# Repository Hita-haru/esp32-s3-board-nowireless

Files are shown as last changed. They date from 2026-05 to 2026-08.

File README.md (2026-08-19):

# ESP32-S3-NoWireless-board
## Description
This is a devboard built using just the ESP32-S3 chip.
## Reason for Creation
Given the ESP32-S3’s AI capabilities and high performance, I wanted to create a program that connects a camera and analyzes its footage using  
AI. However, most inexpensive development boards lack technical compliance certification, and without it, powering them on in Japan would be illegal, forcing me to use a more expensive model.  
This makes it difficult to popularize affordable AI cameras, which is why I decided to build this.  

## How to assemble
1. Manufacture or order the components and circuit board.
2. Solder the components to the circuit board with all your might.
3. Connect it to a computer using a Type-C cable and flash the firmware.
4. After that, you’re free to use it however you like.

## How to Flash Firmware to Custom ESP32-S3 via Arduino IDE
1. Install Board Package
Open Arduino IDE and go to Preferences.

Add this URL to Additional Boards Manager URLs:

[https://raw.githubusercontent.com/espressif/arduino-esp32/gh-pages/package_esp32_index.json](https://raw.githubusercontent.com/espressif/arduino-esp32/gh-pages/package_esp32_index.json)

Open Tools > Board > Boards Manager, search for esp32, and install it.

2. Select Board Settings
Board: ESP32S3 Dev Module

USB CDC On Boot: Enabled (Crucial if using direct ESP32-S3 USB pins IO19/IO20 for Serial output)

Port: Select your board's COM port.

3. Enter Download (Bootloader) Mode
(If your custom board does not have an auto-reset circuit)

Press and HOLD the BOOT button (GPIO0).

Press and RELEASE the RESET (EN) button.

RELEASE the BOOT button.

4. Upload
Click the Upload button in Arduino IDE.

Once the upload is complete, press the RESET button once to run your code!

## Pictures
### Schematic
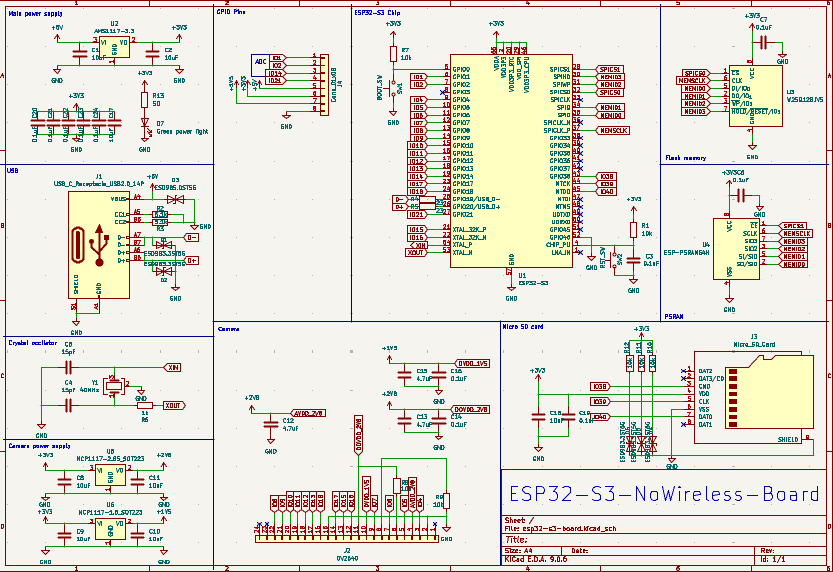
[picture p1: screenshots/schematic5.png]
Schematic

### PCB
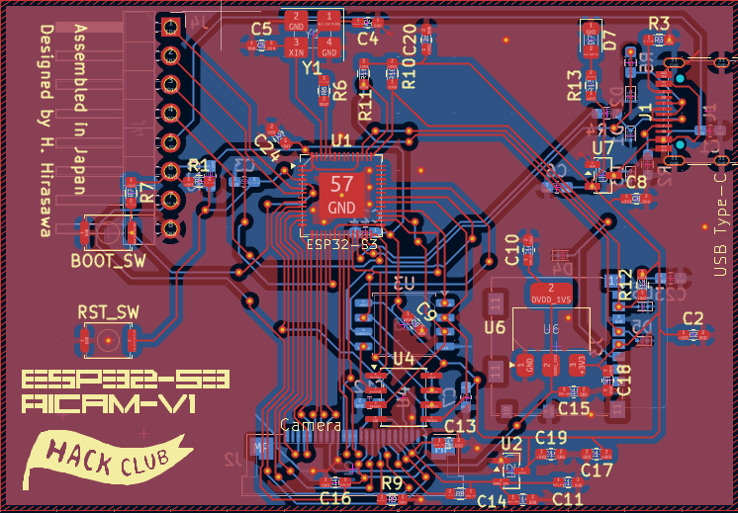
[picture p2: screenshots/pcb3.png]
PCB

### 3D
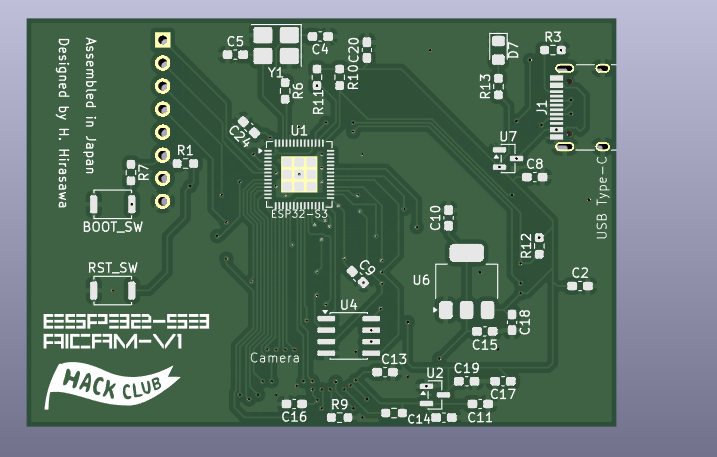
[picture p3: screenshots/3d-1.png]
3D-1

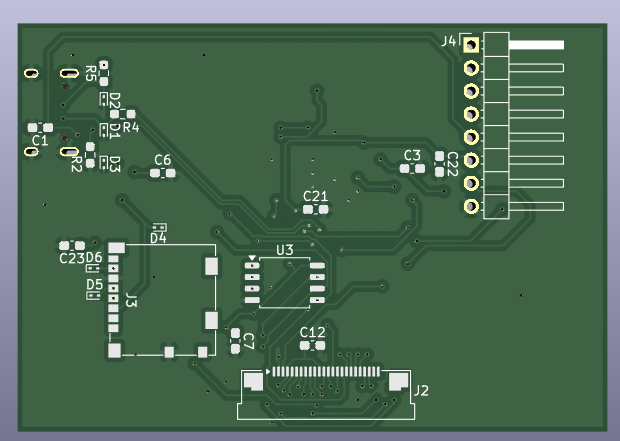
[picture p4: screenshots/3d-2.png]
3D-2

### Estimates
- JLCPCB  
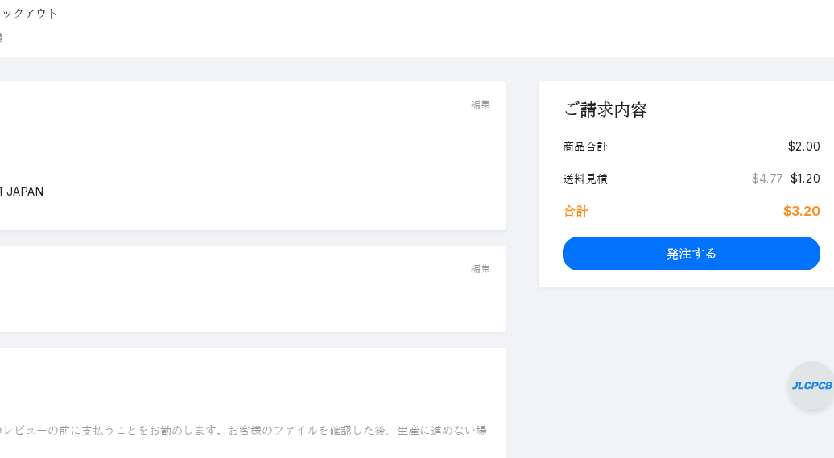
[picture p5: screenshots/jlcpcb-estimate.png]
JLCPCB Estimate1
  
**Shipping options**  
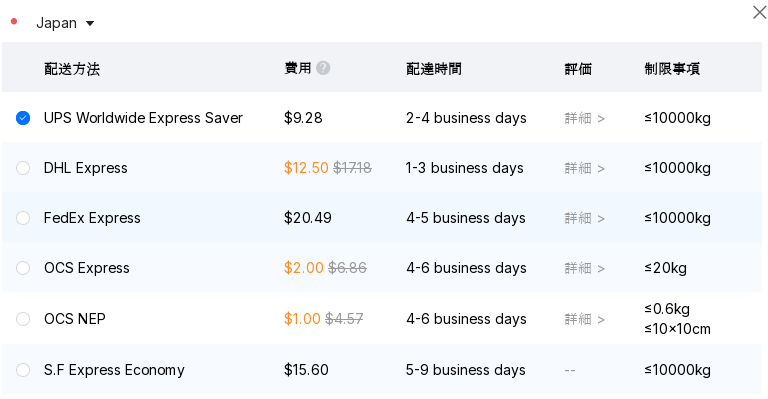
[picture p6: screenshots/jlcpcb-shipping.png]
JLCPCB Estimate2
  
- LCSC  
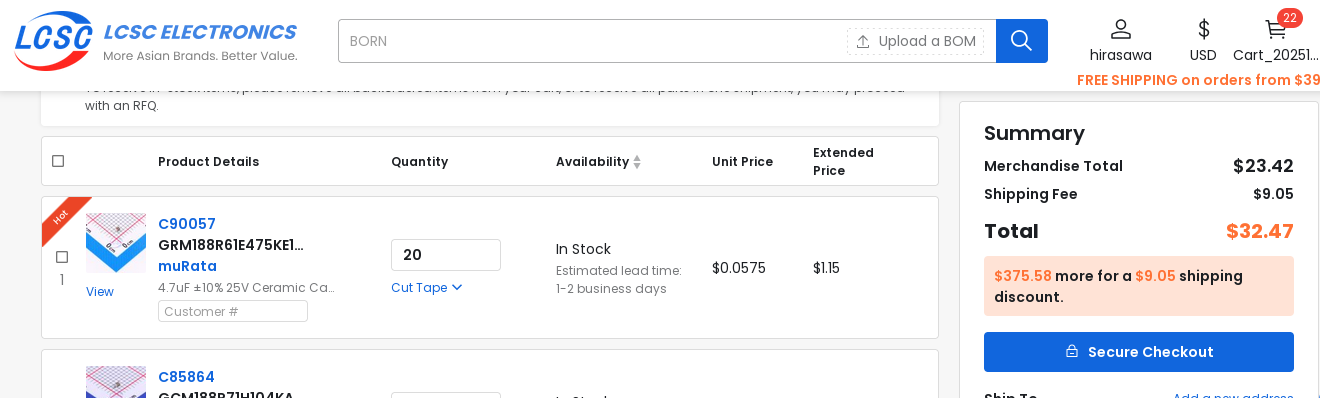
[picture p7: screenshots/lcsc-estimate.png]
LCSC Estimate1
  
**Shipping options**  
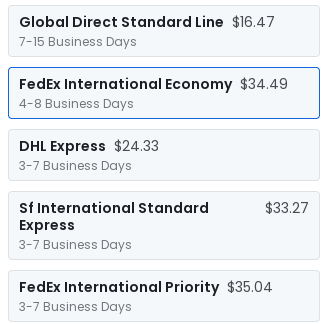
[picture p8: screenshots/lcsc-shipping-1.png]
LCSC Estimate2

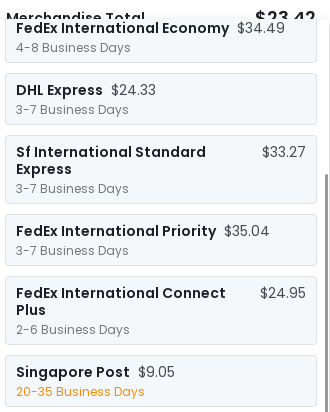
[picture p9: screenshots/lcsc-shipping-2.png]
LCSC Estimate3
  
- Aliexpress  
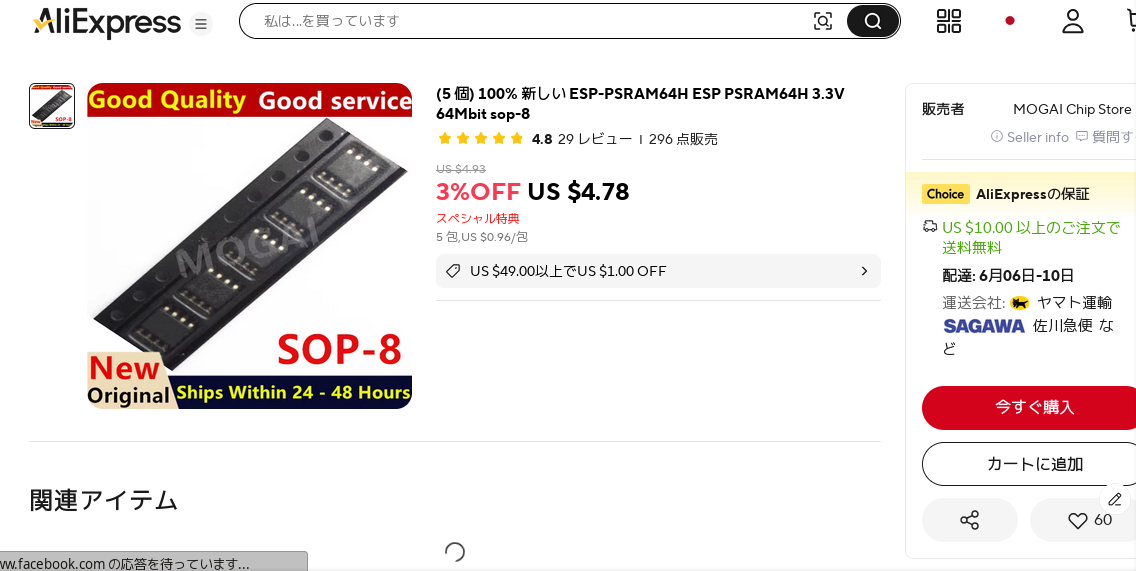
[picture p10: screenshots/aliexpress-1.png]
Aliexpress Estimate1
  
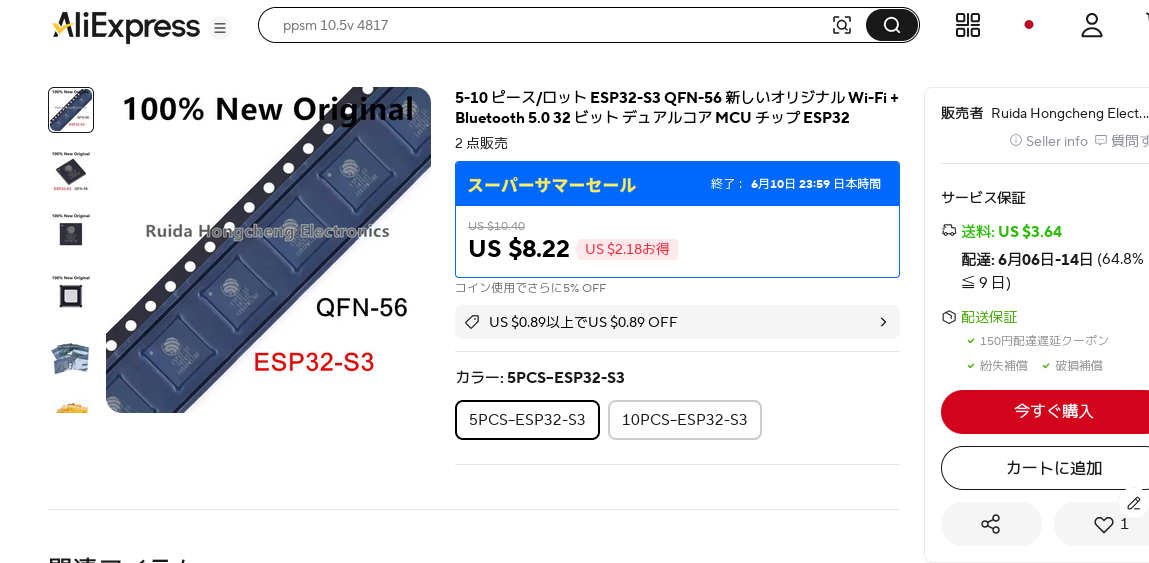
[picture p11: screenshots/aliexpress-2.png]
Aliexpress Estimate2
  

## Cost details
### LCSC
- Subtotal for items  
*23.51* USD  
- Shipping fee (to Japan)  
*9.05* USD
- **Total**  
*32.50* USD (Including discount)  
### Aliexpress
- Subtotal for items  
*13.14* USD  
- Shipping fee (to Japan)  
*5.62* USD  
- **Total**  
*18.76* USD  
### JLCPCB
- Subtotal for items  
*4.00* USD  
- Shipping fee (to Japan)  
*1.00* USD (Including discount)  
- **Total**  
*5.00* USD (Including discount)  

## BOM
| No. | リファレンス (Designators) | 部品名 / 値 (Value) | フットプリント (Footprint) | 数量 | 単価 ($) | URL |
|:---|:---|:---|:---|:---|:---|:---|
| 1 | C13, C15, C12 | 4.7uF | C_0603_1608Metric_Pad1.08x0.95mm_HandSolder | 3 | 0.0675 | https://www.lcsc.com/product-detail/C90057.html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 |
| 2 | C16, C14, C19, C20, C24, C7, C22, C21, C23, C6, C3 | 0.1uF | C_0603_1608Metric_Pad1.08x0.95mm_HandSolder | 11 | 0.0161 | https://www.lcsc.com/product-detail/C85864.html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 |
| 3 | R7, R12, R11, R9, R1, R10, R8 | 10k | R_0603_1608Metric_Pad0.98x0.95mm_HandSolder | 7 | 0.0038 | https://www.lcsc.com/product-detail/C130232.html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 |
| 4 | C9, C8, C10, C17, C2, C18, C11, C1 | 10uF | C_0603_1608Metric_Pad1.08x0.95mm_HandSolder | 8 | 0.0230 | https://www.lcsc.com/product-detail/C7307463.html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 |
| 5 | U6 | NCP1117-1.5_SOT223 | SOT-223-3_TabPin2 | 1 | 0.0684 | https://www.lcsc.com/product-detail/C5380421.html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 |
| 6 | RST_SW | RST_SW | SW_Push_SPST_NO_Alps_SKRK | 1 | 0.1457 | https://www.lcsc.com/product-detail/C202388.html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 |
| 7 | U7 | MCP1700x-330xxTT | SOT-23 | 1 | 0.0886 | https://www.lcsc.com/product-detail/C7551026.html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 |
| 8 | Y1 | 40MHz | Crystal_SMD_3225-4Pin_3.2x2.5mm_HandSoldering | 1 | 0.2632 | https://www.lcsc.com/product-detail/C255943.html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 |
| 9 | R13 | 50 | R_0603_1608Metric_Pad0.98x0.95mm_HandSolder | 1 | 0.0312 | https://www.lcsc.com/product-detail/C849792.html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 |
| 10 | U1 | ESP32-S3 | QFN-56-1EP_7x7mm_P0.4mm_EP4x4mm | 1 | 1.64 | https://ja.aliexpress.com/item/1005012279323107.html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 |
| 11 | R6 | 1k | R_0603_1608Metric_Pad0.98x0.95mm_HandSolder | 1 | 0.0066 | https://www.lcsc.com/product-detail/C118155.html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 |
| 12 | C4, C5 | 15pF | C_0603_1608Metric_Pad1.08x0.95mm_HandSolder | 2 | 0.0066 | https://www.lcsc.com/product-detail/C71651.html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 |
| 13 | U2 | MCP1700x-280xxTT | SOT-23 | 1 | 0.0354 | https://www.lcsc.com/product-detail/C236702.html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 |
| 14 | BOOT_SW | BOOT_SW | SW_Push_SPST_NO_Alps_SKRK | 1 | 0.1457 | https://www.lcsc.com/product-detail/C202388.html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 |
| 15 | J1 | USB_C_Receptacle_USB2.0_14P | USB_C_Receptacle_HRO_TYPE-C-31-M-12 | 1 | 0.1870 | https://www.lcsc.com/product-detail/C165948.html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 |
| 16 | D7 | Green power light | LED_0805_2012Metric_Pad1.15x1.40mm_HandSolder | 1 | 0.0332 | https://www.lcsc.com/product-detail/C192319.html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 |
| 17 | R3, R2 | 5.1k | R_0603_1608Metric_Pad0.98x0.95mm_HandSolder | 2 | 0.0078 | https://www.lcsc.com/product-detail/C160048.html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 |
| 18 | U4 | ESP-PSRAM64H | SOIC-8_3.9x4.9mm_P1.27mm | 1 | 0.956 | https://ja.aliexpress.com/item/1005009178803030.html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 |
| 19 | D6, D2, D4, D5, D1 | ESD9B3.3ST5G | D_SOD-923 | 5 | 0.0154 | https://www.lcsc.com/product-detail/C51898359.html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 |
| 20 | J3 | Micro_SD_Card | microSD_HC_Molex_104031-0811 | 1 | 0.6804 | https://www.lcsc.com/product-detail/C585350.html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 |
| 21 | R5, R4 | 23 | R_0603_1608Metric_Pad0.98x0.95mm_HandSolder | 2 | 0.0020 | https://www.lcsc.com/product-detail/C2612468.html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 |
| 22 | U3 | W25Q128JVS | SOIC-8_5.3x5.3mm_P1.27mm | 1 | 2.6399 | https://www.lcsc.com/product-detail/C97521.html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 |
| 23 | J4 | Conn_01x08 | PinHeader_1x08_P2.54mm_Horizontal | 1 | 0.0734 | https://www.lcsc.com/product-detail/C7501270.html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 |
| 24 | J2 | OV2640 | Amphenol_F32Q-1A7x1-11024_1x24-1MP_P0.5mm_Horizontal | 1 | 2.1342 | https://www.lcsc.com/product-detail/C3168917.html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 |
| 25 | D3 | ESD9B5.0ST5G | D_SOD-923 | 1 | 0.0457 | https://www.lcsc.com/product-detail/C82326.html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 |
| 26 | - | PCB | - | 1 | 0.8 | https://cart.jlcpcb.com/jp/quote |

## Credits & Acknowledgements
This hardware design is based on / derived from the [ESP32-S3-EYE](https://github.com/espressif/esp-dev-kits) reference design created by **Espressif Systems**. Special thanks to Espressif for providing open-source hardware reference designs.

## Trademarks
- "ESP32", "ESP32-S3", and "Espressif" are registered trademarks or trademarks of **Espressif Systems (Shanghai) Co., Ltd.**
- All other trademarks and logos are the property of their respective owners.

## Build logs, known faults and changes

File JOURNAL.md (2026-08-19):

---
title: "ESP32-S3-board-nowireless"
author: "ひらさわ"
description: "This is ESP32-S3 devboard"
created_at: "2026-05-20"
---

# 5/20: Created project and designed schematic
I Created project and Kicad files.  
I’ve drawn up a schematic as well. At first, I was thinking of using WROOM, but since the versions with Technical Conformity Mark are expensive, To reduce costs, we opted for the standalone chip instead of the ESP32-S3 WROOM module.  

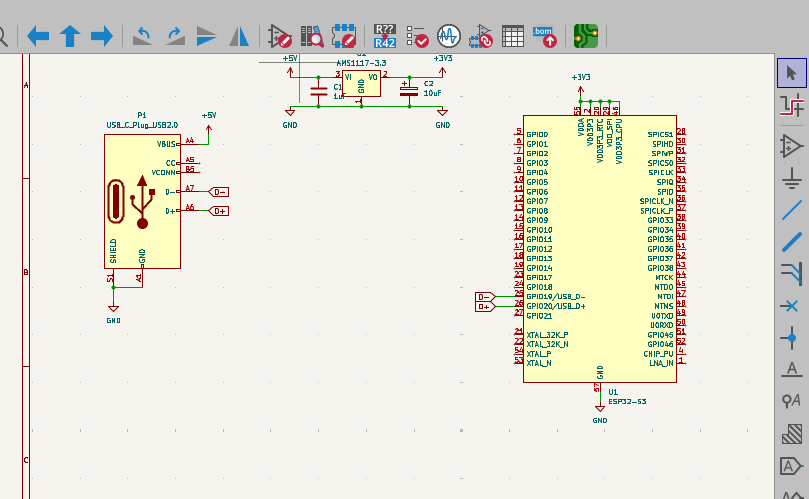
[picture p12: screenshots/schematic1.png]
schematic
  
**Total time spent: 2 hours**

# 5/22: Set up git and added crystal oscillator and so on
I set up GitHub.  
I also added a crystal oscillator and modified the USB connector.  
Unfortunately, there wasn’t much documentation available, so I ended up spending quite a bit of time searching for information.  

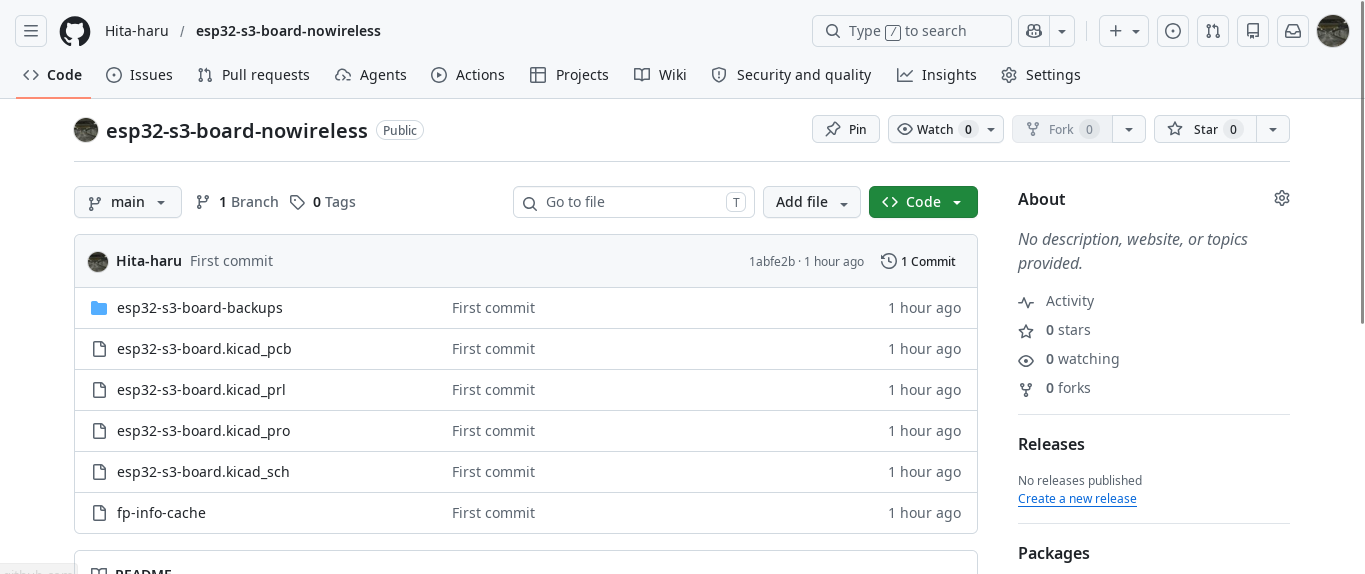
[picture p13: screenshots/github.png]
Github

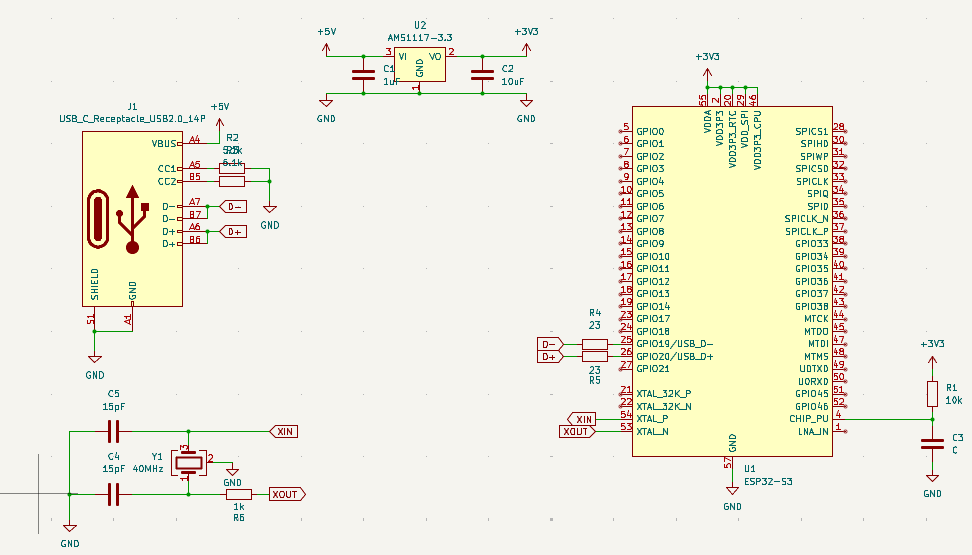
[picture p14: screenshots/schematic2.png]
Schematic
  
**Total time spent: 2 hours**

# 5/23: Added flash memory and PSRAM to the schematic
I added flash memory and PSRAM to the circuit diagram.  
As usual, there was no detailed documentation, so I added them while referring to the Blueprint's guide.  
Other than that, I just added a connector for attaching a camera.  
It took me forever to find the documentation, so it was a real hassle.  

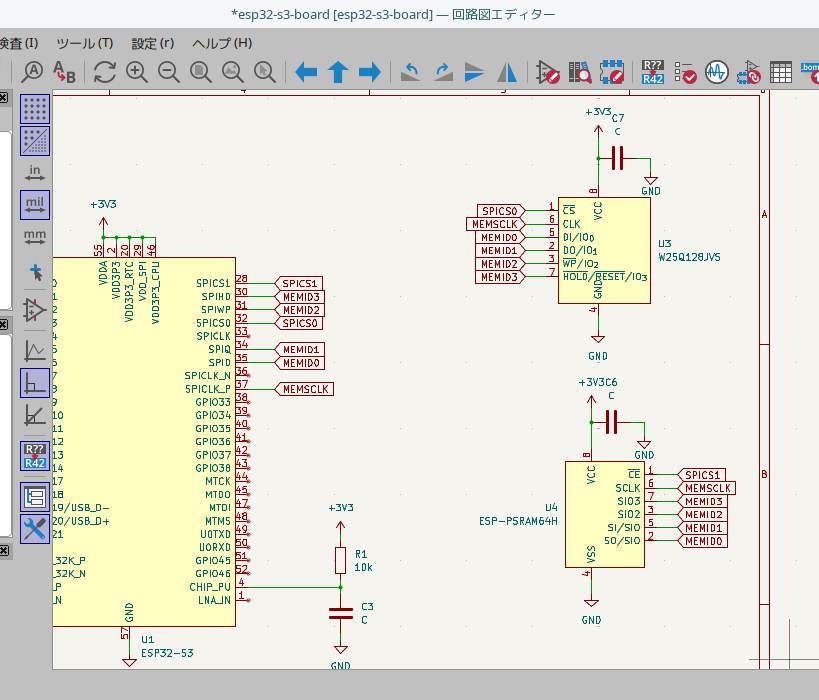
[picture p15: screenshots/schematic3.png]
Schematic
  
**Total time spent: 2 hours**

# 5/26: Added camera and power supply to the schematic
Today, I added the camera module (24-pin FPC connector for the OV2640) and the power supply module for the 3.3V line (such as the AMS1117-3.3) to the circuit diagram, using the ESP32-S3-EYE circuit diagram as a reference.  
I think it will be quite difficult because there will likely be a lot of noise.  

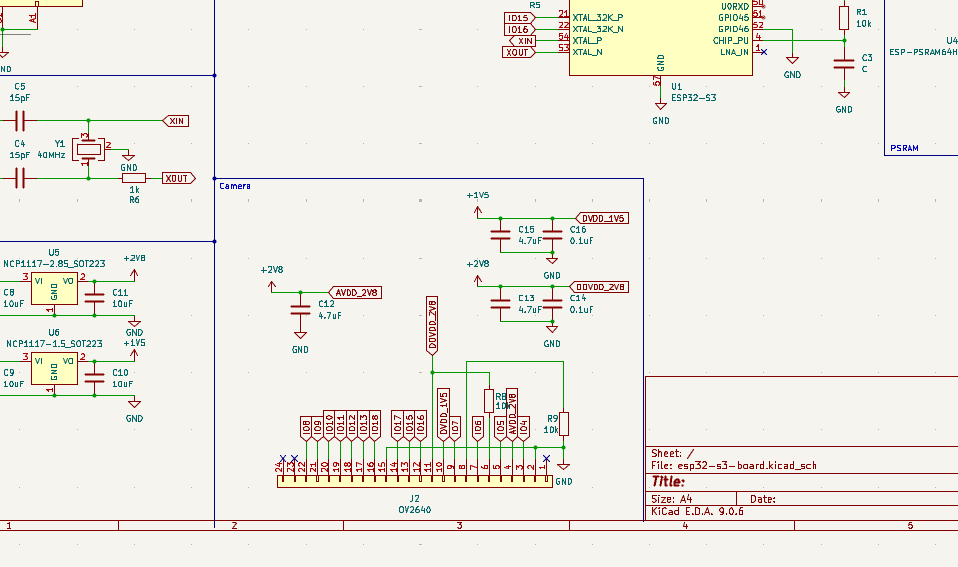
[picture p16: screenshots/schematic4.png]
Schematic
  
**Total time spent: 2 hours**

# 5/27: Finished writing schematic
I finished drawing the circuit diagram today.  
Lately, I’ve been working on it for about an hour in the morning and three hours at night, but I got so absorbed in it that I ended up working on it for six hours.  
I have midterms coming up at school, but I haven’t studied at all—this is bad.  

Schematic  
**Total time spent: 2 hours**

# 5/28: Assigned the footprint.
This time, I assigned the footprints.
I was assigning them by comparing them with various documents and the parts we plan to purchase, but it was difficult to determine which footprint some of the parts should be assigned to, so I ended up struggling more than I expected. 

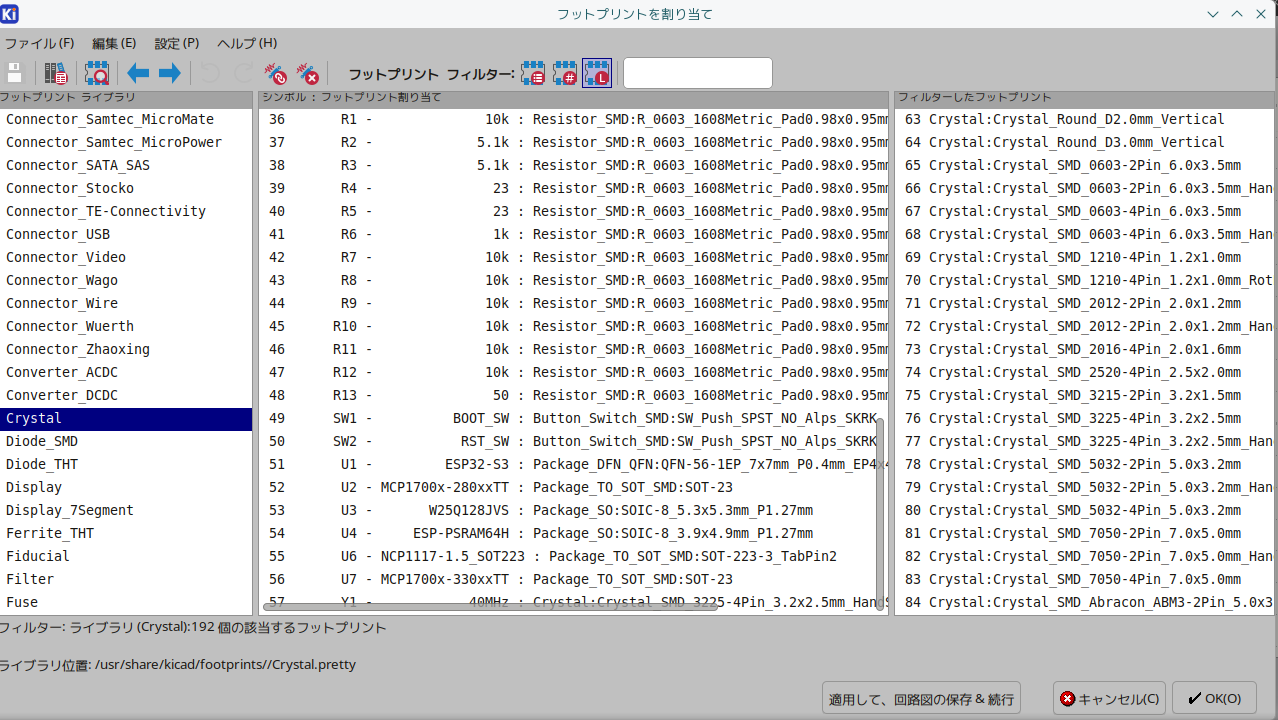
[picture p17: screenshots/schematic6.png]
Schematic
  
**Total time spent: 0.5 hours**

# 5/29: Routed for the first time
This time, I worked on routing the PCB.  
It was a total mess, and it really made my head spin, but as I worked on it, it started to feel like I was solving a puzzle, and I got so absorbed in it that before I knew it, it was 11 p.m.  

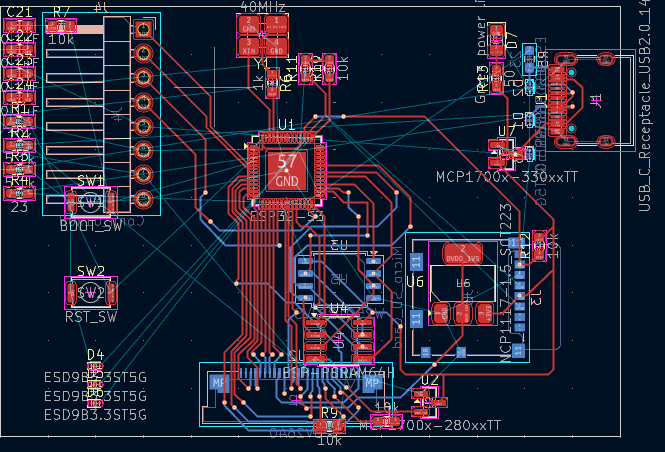
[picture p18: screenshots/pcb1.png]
  
**Total time spent: 3.5 hours**

# 5/30: Finished routing PCB around main chip
I couldn’t bring myself to study today, so I spent the whole day working on the PCB layout.  
I’ve finished routing the main chip, flash memory, and PSRAM.  
It was quite a challenge figuring out the noise countermeasures, so it was tough going.  
I’ll be happy if it works.  

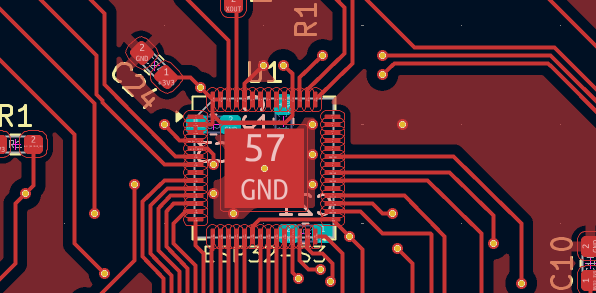
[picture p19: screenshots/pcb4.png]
  
**Total time spent: 3 hours**

# 5/30: Finished routing PCB
I've finished all the wiring.  
I installed the USB connector, TF card slot, and other components.  
I spent the whole day working on this, so I'm worried about my midterms.  

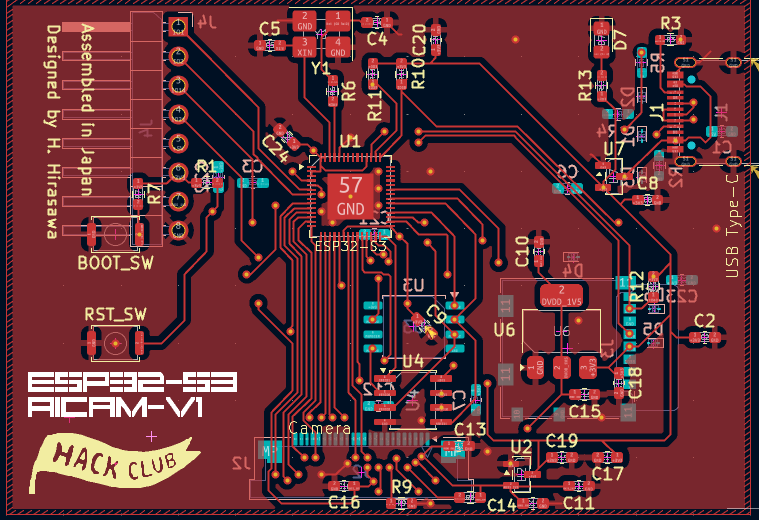
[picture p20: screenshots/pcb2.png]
  
**Total time spent: 2 hours**  

# 5/31: Created quotes from JLCPCB and LCSC
Today, I created a quote for JLCPCB. I’m also in the middle of creating a quote for LCSC.  
Since I’m entering everything manually based on the BOM, it’s quite time-consuming.  
Also, I’ll add a screenshot of the “Journal” feature—the previous one only showed the front side.  

PCB
JLCPCB Estimate1
JLCPCB Estimate2  
**Total time spent: 2 hours**

# 6/1: Created quotes from LCSC and Aliexpress
Today, I requested quotes from LCSC and AliExpress.  
Now that I’m ready to place the order, all I can do is hope it passes the review process.  

LCSC Estimate1  
LCSC Estimate2  
LCSC Estimate3  
Aliexpress Estimate1  
Aliexpress Estimate2  
**Total time spent: 1.5 hours**  

# 6/2: Fixed README.md and fabrication files
Today, I fixed the issues pointed out in the review.  
I regenerated the build files and added a link to the BOM in README.md, so I think it should work now.  

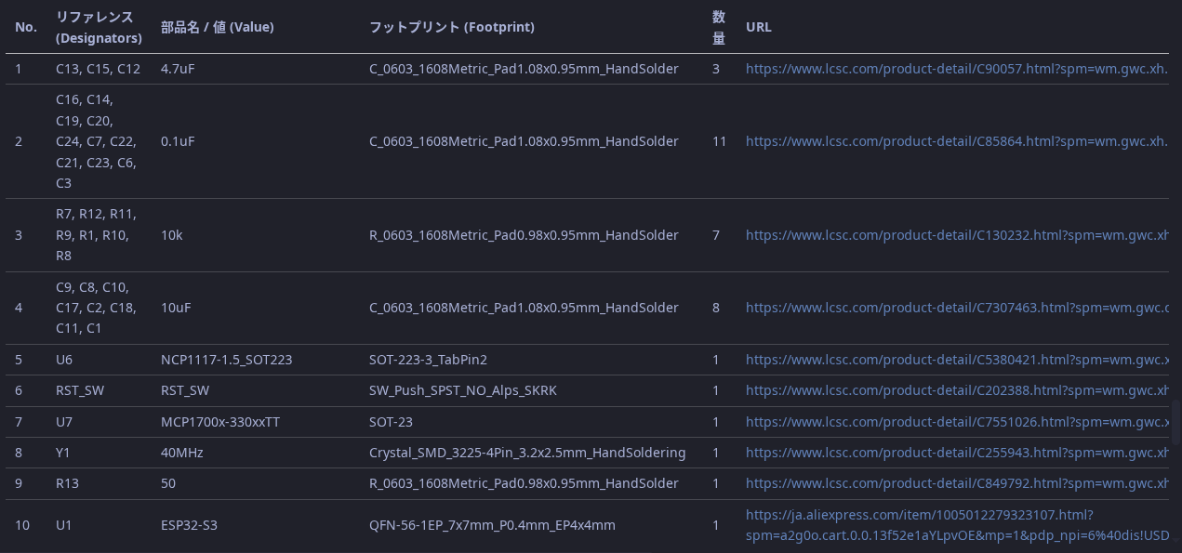
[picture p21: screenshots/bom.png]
BOM Preview
  
**Total time spent: 1 hours**  

# 6/4: Updated the JOURNAL.md file and the PCB
Today, I made some changes to JOURNAL.md and the PCB.  
The PCB was primarily designed to ensure that the USB signal lines were of equal length.  
I don't think I've finished revising JOURNAL.md and the rest just yet, so I plan to continue working on them tomorrow.  

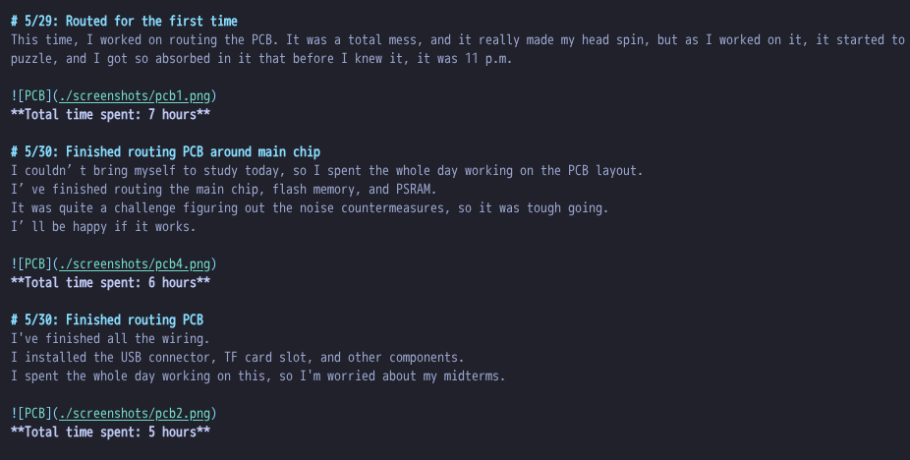
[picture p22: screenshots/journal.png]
Updated JOURNAL.md
  
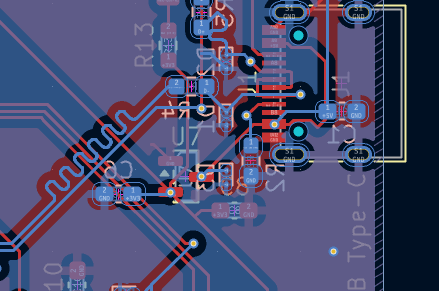
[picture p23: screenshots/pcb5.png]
Updated PCB
  
**Total time spent: 1.5 hours**

# 6/6: Updated the README.md
I updated the README.md today.  
I went to school yesterday and was out all day, so I did it today.  
I made sure it meets all the requirements, so I hope the review goes through.  

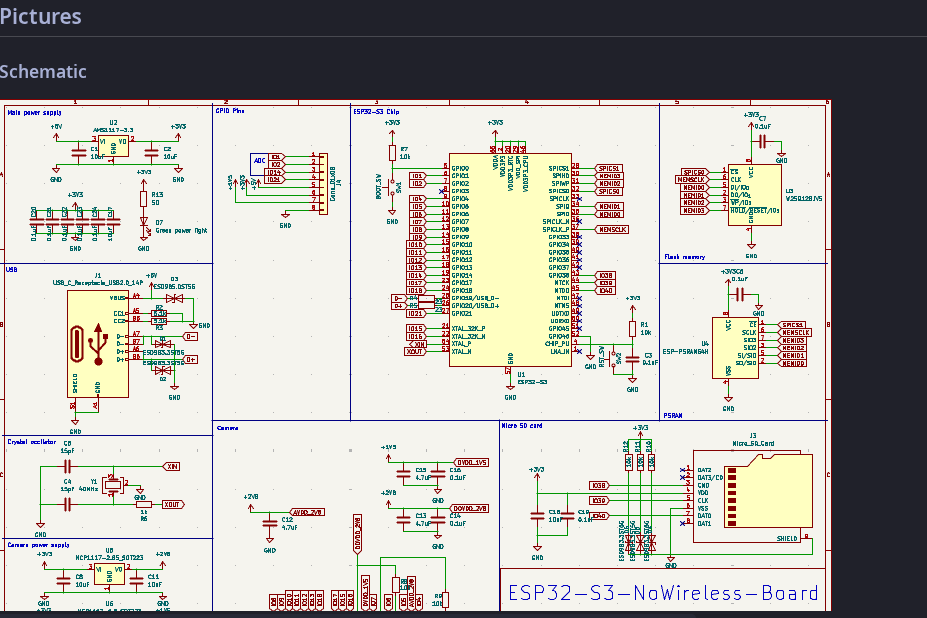
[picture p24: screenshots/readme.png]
Updated README.md

**Total time spent: 0.5 hours**

# 6/6: Updated the README.md and added gerber.zip
I've updated README.md again.  
I've added information about costs to the BOM and the newly created section.  
Also, I forgot to create the gerber.zip file, so I've created it now.  

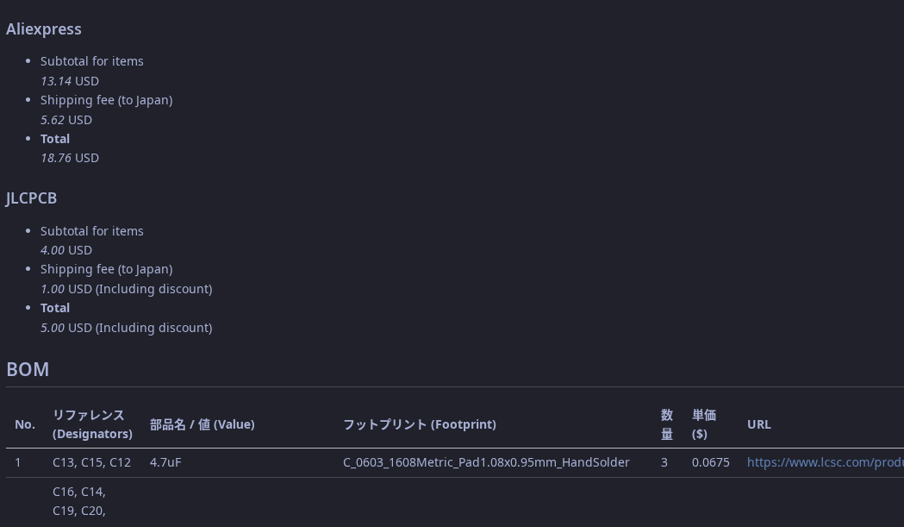
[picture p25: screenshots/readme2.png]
Updated README.md

**Total time spent: 1 hours**

# 6/19: Updated the JOURNAL.md
I took another look at this, and since I’d recorded the times vaguely, it’s clear that I’ve logged way too much time. It’s my fault for just recording them casually, thinking, “This should be about right.” I’m really sorry...
I’ve roughly halved all the recorded times, so I’d be happy if this gets approved.
I’ll use a stopwatch from now on.

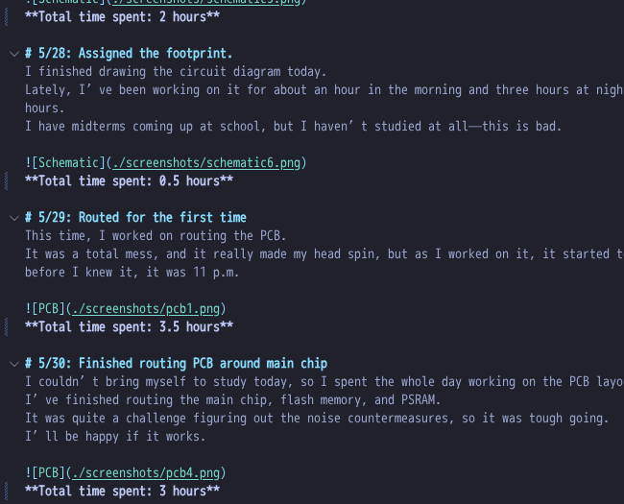
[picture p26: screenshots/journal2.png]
Updated JOURNAL.md

**Total time spent: 0.5 hours**

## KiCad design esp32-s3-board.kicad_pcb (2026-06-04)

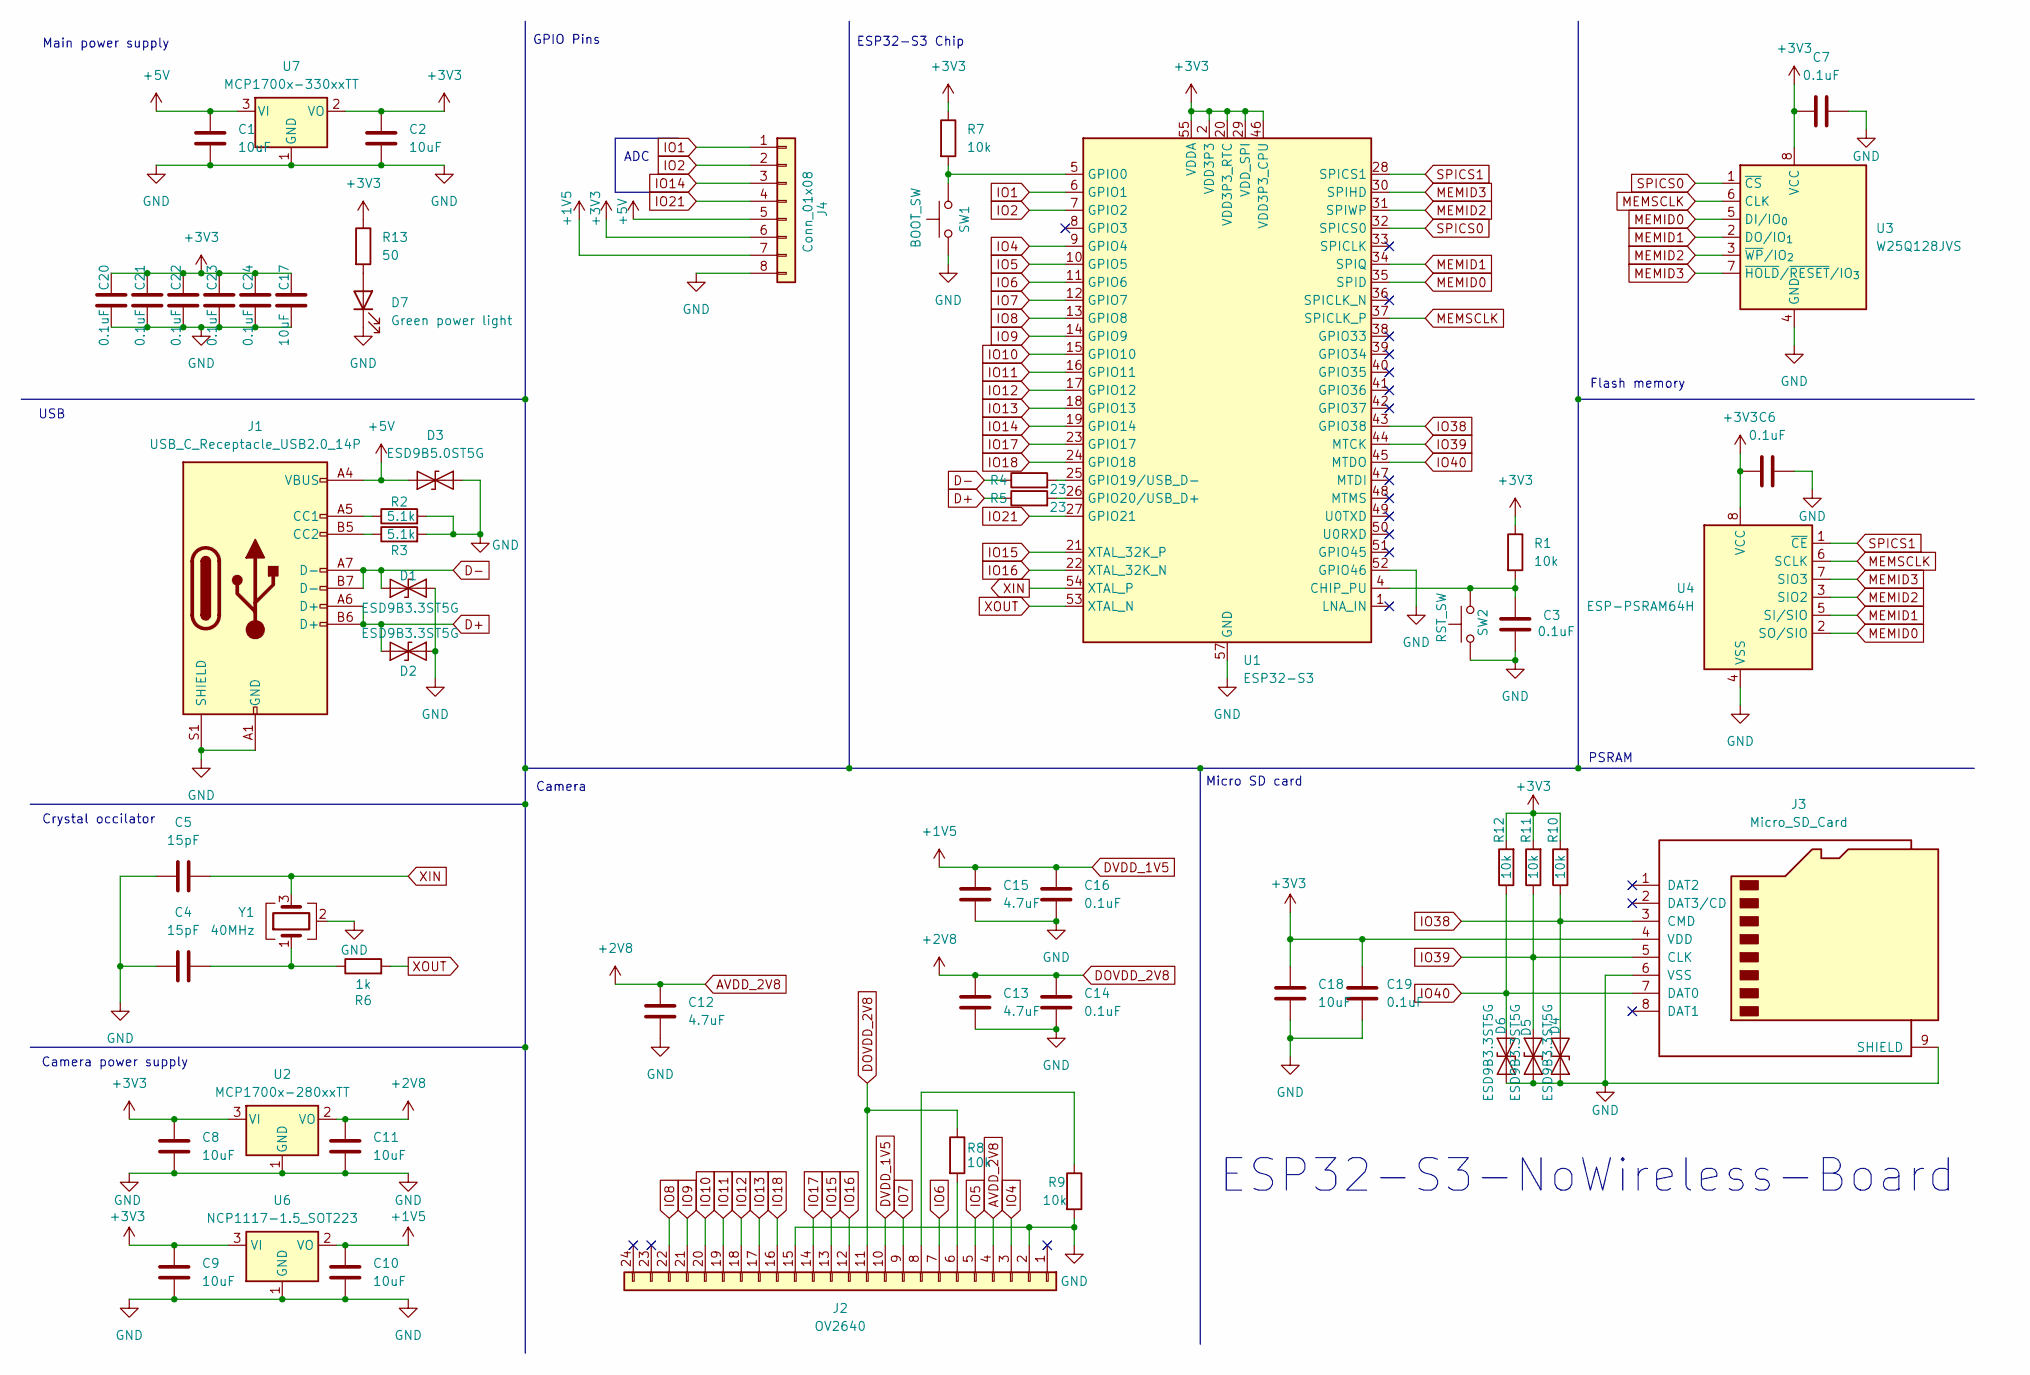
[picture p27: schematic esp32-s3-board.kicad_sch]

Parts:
C1, C2, C8, C9, C10, C11, C17, C18: 10uF; C_0603_1608Metric_Pad1.08x0.95mm_HandSolder
C3, C6, C7, C14, C16, C19, C20, C21, C22, C23, C24: 0.1uF; C_0603_1608Metric_Pad1.08x0.95mm_HandSolder
C4, C5: 15pF; C_0603_1608Metric_Pad1.08x0.95mm_HandSolder
C12, C13, C15: 4.7uF; C_0603_1608Metric_Pad1.08x0.95mm_HandSolder
D1, D2, D4, D5, D6: ESD9B3.3ST5G; D_SOD-923
D3: ESD9B5.0ST5G; D_SOD-923
D7: Green power light; LED_0805_2012Metric_Pad1.15x1.40mm_HandSolder
J1: USB_C_Receptacle_USB2.0_14P; USB_C_Receptacle_HRO_TYPE-C-31-M-12
J2: OV2640; Amphenol_F32Q-1A7x1-11024_1x24-1MP_P0.5mm_Horizontal
J3: Micro_SD_Card; microSD_HC_Molex_104031-0811
J4: Conn_01x08; PinHeader_1x08_P2.54mm_Horizontal
R1, R7, R8, R9, R10, R11, R12: 10k; R_0603_1608Metric_Pad0.98x0.95mm_HandSolder
R2, R3: 5.1k; R_0603_1608Metric_Pad0.98x0.95mm_HandSolder
R4, R5: 23; R_0603_1608Metric_Pad0.98x0.95mm_HandSolder
R6: 1k; R_0603_1608Metric_Pad0.98x0.95mm_HandSolder
R13: 50; R_0603_1608Metric_Pad0.98x0.95mm_HandSolder
SW1: BOOT_SW; SW_Push_SPST_NO_Alps_SKRK
SW2: RST_SW; SW_Push_SPST_NO_Alps_SKRK
U1: ESP32-S3; QFN-56-1EP_7x7mm_P0.4mm_EP4x4mm
U2: MCP1700x-280xxTT; SOT-23
U3: W25Q128JVS; SOIC-8_5.3x5.3mm_P1.27mm
U4: ESP-PSRAM64H; SOIC-8_3.9x4.9mm_P1.27mm
U6: NCP1117-1.5_SOT223; SOT-223-3_TabPin2
U7: MCP1700x-330xxTT; SOT-23
Y1: 40MHz; Crystal_SMD_3225-4Pin_3.2x2.5mm_HandSoldering

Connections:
+3V3: C2.1, C6.1, C7.1, C8.1, C9.1, C17.1, C18.1, C19.1, C20.1, C21.1, C22.1, C23.1, C24.1, J3.4 (VDD), J4.6, R1.1, R7.1, R10.2, R11.2, R12.2, R13.1, U1.2 (VDD3P3), U1.3 (VDD3P3), U1.20 (VDD3P3_RTC), U1.29 (VDD_SPI), U1.46 (VDD3P3_CPU), U1.55 (VDDA), U1.56 (VDDA), U2.3 (VI), U3.8 (VCC), U4.8 (VCC), U6.3 (VI), U7.2 (VO)
+5V: C1.1, D3.1 (A1), J1.A4 (VBUS), J1.A9 (VBUS), J1.B4 (VBUS), J1.B9 (VBUS), J4.5, U7.3 (VI)
AVDD_2V8: C11.1, C12.1, C13.1, C14.1, J2.4, J2.11, R8.1, U2.2 (VO)
D+: D2.1 (A1), J1.A6 (D+), J1.B6 (D+), R5.1
D-: D1.1 (A1), J1.A7 (D-), J1.B7 (D-), R4.1
DVDD_1V5: C10.1, C15.1, C16.1, J2.10, J4.7, U6.2 (VO)
GND: C1.2, C2.2, C3.2, C4.1, C5.1, C6.2, C7.2, C8.2, C9.2, C10.2, C11.2, C12.2, C13.2, C14.2, C15.2, C16.2, C17.2, C18.2, C19.2, C20.2, C21.2, C22.2, C23.2, C24.2, D1.2 (A2), D2.2 (A2), D3.2 (A2), D4.1 (A1), D5.1 (A1), D6.1 (A1), D7.1 (K), J1.A1 (GND), J1.A12 (GND), J1.B1 (GND), J1.B12 (GND), J1.S1 (SHIELD), J2.2, J2.15, J3.6 (VSS), J3.9 (SHIELD), J4.8, R2.2, R3.2, R9.2, SW1.1, SW2.1, U1.52 (GPIO46), U1.57 (GND), U2.1 (GND), U3.4 (GND), U4.4 (VSS), U6.1 (GND), U7.1 (GND), Y1.2 (G), Y1.4 (G); also elsewhere on the board
IO1: J4.1, U1.6 (GPIO1)
IO2: J4.2, U1.7 (GPIO2)
IO4: J2.3, U1.9 (GPIO4)
IO5: J2.5, U1.10 (GPIO5)
IO6: J2.7, U1.11 (GPIO6)
IO7: J2.9, U1.12 (GPIO7)
IO8: J2.22, U1.13 (GPIO8)
IO9: J2.21, U1.14 (GPIO9)
IO10: J2.20, U1.15 (GPIO10)
IO11: J2.19, U1.16 (GPIO11)
IO12: J2.18, U1.17 (GPIO12)
IO13: J2.17, U1.18 (GPIO13)
IO14: J4.3, U1.19 (GPIO14)
IO15: J2.13, U1.21 (XTAL_32K_P)
IO16: J2.12, U1.22 (XTAL_32K_N)
IO17: J2.14, U1.23 (GPIO17)
IO18: J2.16, U1.24 (GPIO18)
IO21: J4.4, U1.27 (GPIO21)
IO38: D4.2 (A2), J3.3 (CMD), R10.1, U1.43 (GPIO38)
IO39: D5.2 (A2), J3.5 (CLK), R11.1, U1.44 (MTCK)
IO40: D6.2 (A2), J3.7 (DAT0), R12.1, U1.45 (MTDO)
MEMID0: U1.35 (SPID), U3.5 (DI/IO_{0}), U4.2 (SO/SIO)
MEMID1: U1.34 (SPIQ), U3.2 (DO/IO_{1}), U4.5 (SI/SIO)
MEMID2: U1.31 (SPIWP), U3.3 (~WP/IO_{2}), U4.3 (SIO2)
MEMID3: U1.30 (SPIHD), U3.7 (~HOLD/~RESET/IO_{3}), U4.7 (SIO3)
MEMSCLK: U1.37 (SPICLK_P), U3.6 (CLK), U4.6 (SCLK)
unnamed: C4.2, R6.1, Y1.1
unnamed: D7.2 (A), R13.2
unnamed: J1.A5 (CC1), R2.1
unnamed: J1.B5 (CC2), R3.1
unnamed: J2.6, R8.2
unnamed: J2.8, R9.1
unnamed 39: C3.1, R1.2, SW2.2, U1.4 (CHIP_PU); also elsewhere on the board
unnamed 40: R7.2, SW1.2, U1.5 (GPIO0); also elsewhere on the board
unnamed: R4.2, U1.25 (GPIO19/USB_D-)
unnamed: R5.2, U1.26 (GPIO20/USB_D+)
SPICS0: U1.32 (SPICS0), U3.1 (~CS)
SPICS1: U1.28 (SPICS1), U4.1 (~CE)
XIN: C5.2, U1.54 (XTAL_P), Y1.3
XOUT: R6.2, U1.53 (XTAL_N)

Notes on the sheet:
Crystal occilator
Camera power supply
Main power supply
ESP32-S3 Chip
Camera
ESP32-S3-NoWireless-Board
USB
Flash memory
ADC
GPIO Pins
Micro SD card
PSRAM

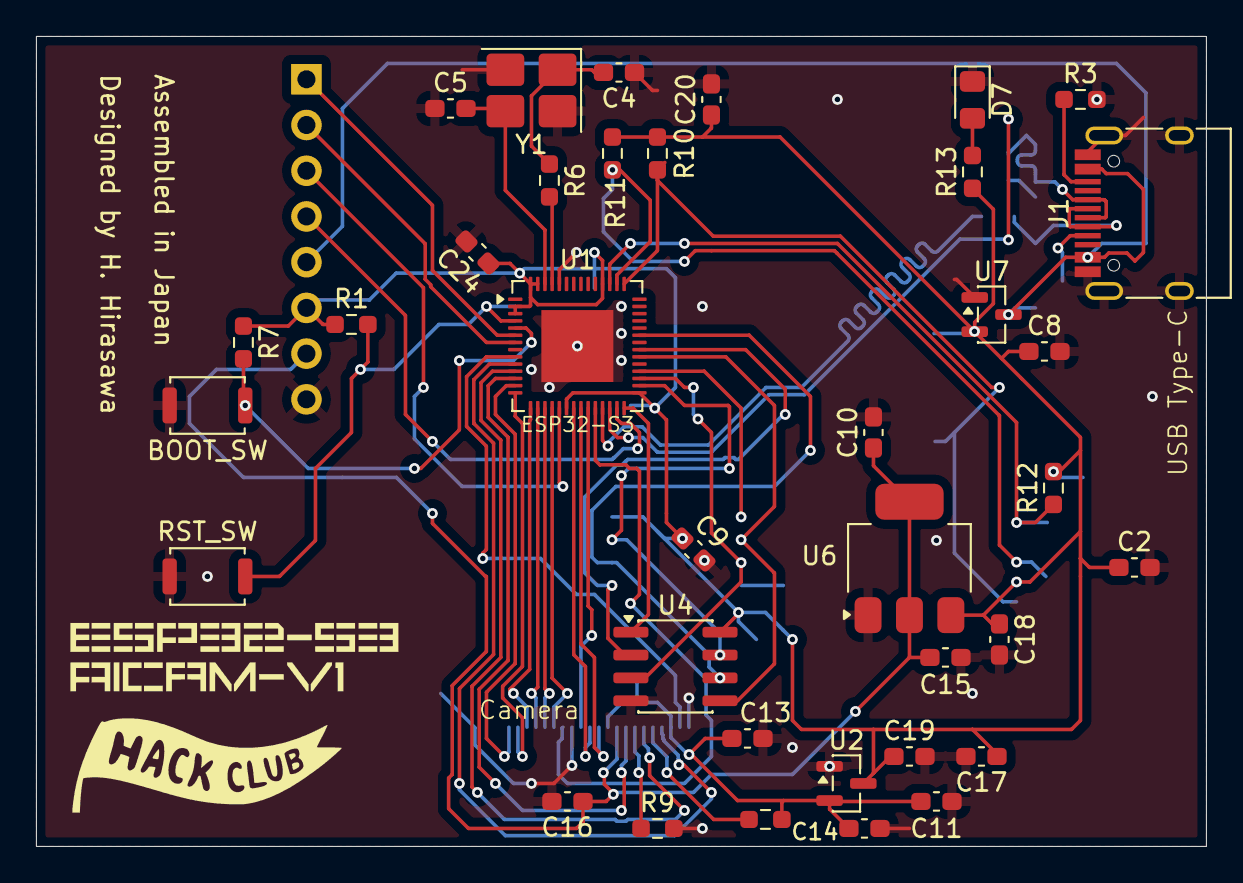
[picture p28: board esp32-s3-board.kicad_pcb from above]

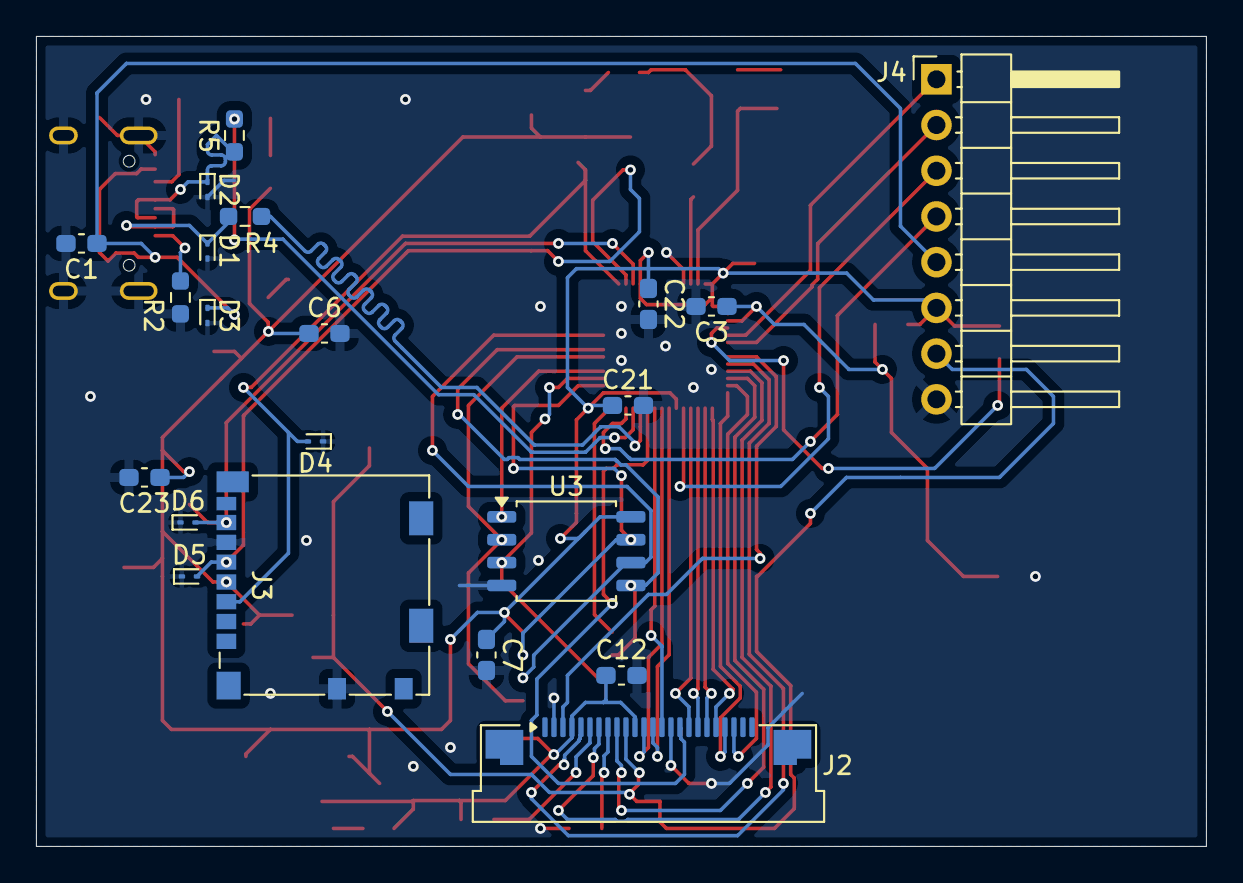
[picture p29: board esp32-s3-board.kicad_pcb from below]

Board: 2 copper layers, 65.0 x 45.0 mm, 57 parts (21 on the bottom side), 47 nets.

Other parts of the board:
BOOT_SW: BOOT_SW; SW_Push_SPST_NO_Alps_SKRK
RST_SW: RST_SW; SW_Push_SPST_NO_Alps_SKRK

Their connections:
GND: BOOT_SW.1, RST_SW.1; also elsewhere on the board
unnamed 39: RST_SW.2; also elsewhere on the board
unnamed 40: BOOT_SW.2; also elsewhere on the board

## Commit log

2026-05-22 Added journal
    [esp32-s3-board.kicad_sch]
2026-05-23 Editted journal
    [esp32-s3-board.kicad_sch]
2026-05-27 Finished writing schematic
    [esp32-s3-board.kicad_sch]
2026-05-28 Assigned footprint
    [esp32-s3-board.kicad_sch]
2026-05-29 Routed PCB for the first time
    [esp32-s3-board.kicad_pcb]
2026-05-30 Finished routing pcb
    [esp32-s3-board.kicad_pcb]
2026-05-31 Created JLCPCB estimate
    [BOM.csv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]
2026-06-01 Created LCSC and Aliexpress estimates
    [BOM.csv]
2026-06-02 Fixed README.md and fabrication files
    [esp32-s3-board-B_Cu.gbr, esp32-s3-board-B_Mask.gbr, esp32-s3-board-B_Paste.gbr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]
